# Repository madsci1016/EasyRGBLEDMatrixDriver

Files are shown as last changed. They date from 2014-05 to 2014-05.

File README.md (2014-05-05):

EasyRGBLEDMatrixDriver
======================

Super Easy Arduino based serial backpack driver board for 16 x 32 RGB LED Matrix panels found here: http://www.adafruit.com/products/420

The code and board  design will let you drive a 16x32 RGB LED matrix panel with a serial port, with some limitations. A example sketch for a master controller is included. 

Video Demo:  http://youtu.be/BNk5QkBuxNQ  

FEATURES:
Drive multiple panels off 1 serial port to create larger displays.

LIMITATIONS:
You only get half the resolution of the 16x32 pixel display, only 8x16 which is then scaled to 16x32
Refresh rate is limited by speed and number of displays on the Serial Port

This library runs off of an Arduino Pro/Uno which is NOT powerful enough to display video. It's really meant for animations, text, and Tetris among other things.  

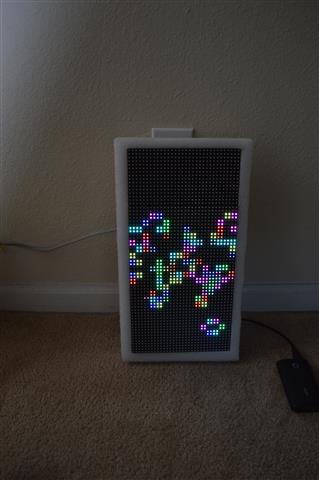
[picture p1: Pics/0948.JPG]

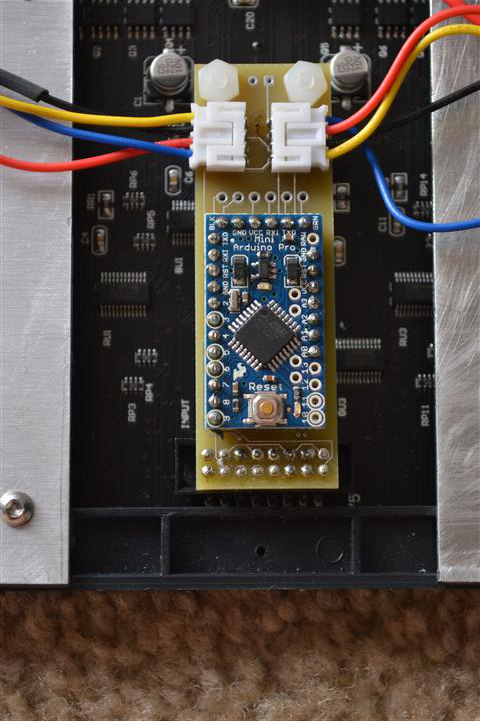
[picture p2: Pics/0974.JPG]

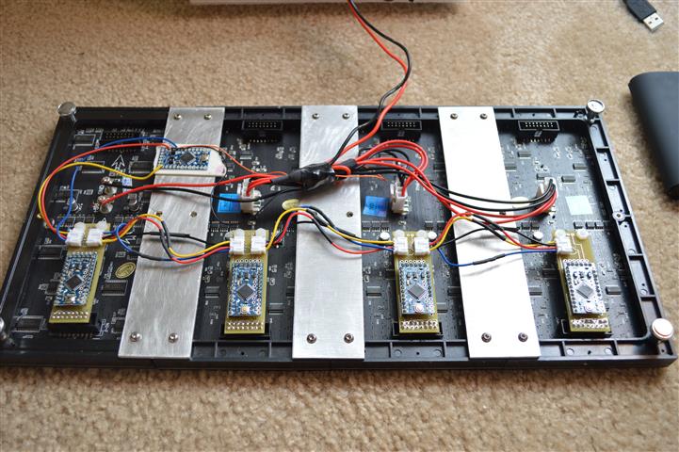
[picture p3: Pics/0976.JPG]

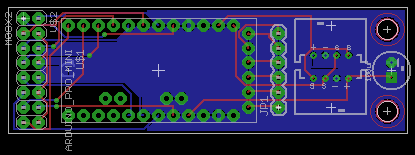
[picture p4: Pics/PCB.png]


In those pictures only 3 wires are shared by the 4 backpack Arduinos, 5V (Blue), GND (RED) and Data (Yellow) which is connected to the Serial RX of each Arduino (pin 1) the black wire (connected to TX of each Arduino) is not connected between each board. 

The 5th Arduino is the 'Master' and the Data line (Yellow) connects to it's Serial TX pin (Pin 0). 

Arduinos: https://www.sparkfun.com/products/11113
Wire and plug: https://www.sparkfun.com/products/9916

REQUIRES THE FOLLOWING LIBRARIES: 

https://github.com/adafruit/Adafruit-GFX-Library
https://github.com/adafruit/RGB-matrix-Panel
https://github.com/madsci1016/Arduino-EasyTransfer

To wire the display to the backpack arduino (Without my PCB), see:
https://learn.adafruit.com/32x16-32x32-rgb-led-matrix/wiring-the-16x32-matrix

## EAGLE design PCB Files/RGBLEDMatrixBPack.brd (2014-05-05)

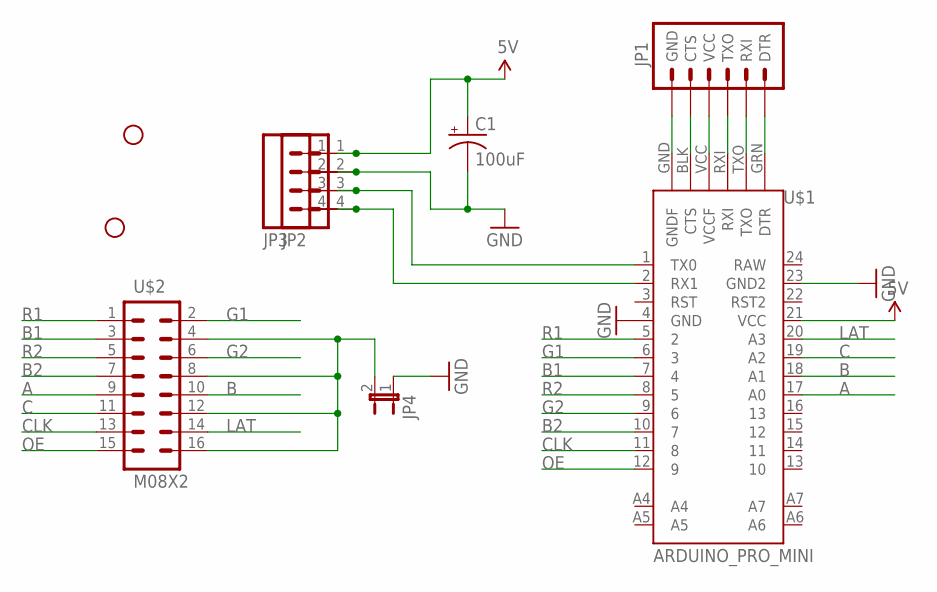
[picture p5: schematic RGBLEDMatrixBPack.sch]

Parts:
C1: 100uF; CPOL-RADIAL-100UF-25V
JP1: ARDUINO_SERIAL_PROGRAMPTH; 1X06
JP2, JP3: M04JST-PTH; JST-4-PTH
JP4: JUMPER-2SMD-NO; SJ_2S-NO
STANDOFF1, STANDOFF2: STAND-OFF
U$1: ARDUINO_PRO_MINI
U$2: M08X2; 2X8

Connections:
5V: C1.1 (+), JP2.1, JP3.1, U$1.21 (VCC)
A: U$1.17 (A0), U$2.9
B: U$1.18 (A1), U$2.10
B1: U$1.7 (4), U$2.3
B2: U$1.10 (7), U$2.7
C: U$1.19 (A2), U$2.11
CLK: U$1.11 (8), U$2.13
G1: U$1.6 (3), U$2.2
G2: U$1.9 (6), U$2.6
GND: C1.2 (-), JP2.2, JP3.2, JP4.1, U$1.4 (GND), U$1.23 (GND2)
LAT: U$1.20 (A3), U$2.14
unnamed: JP1.1 (DTR), U$1.GRN (DTR)
unnamed: JP1.2 (RXI), U$1.TXO
unnamed: JP1.3 (TXO), U$1.RXI
unnamed: JP1.4 (VCC), U$1.VCC (VCCF)
unnamed: JP1.5 (CTS), U$1.BLK (CTS)
unnamed: JP1.6 (GND), U$1.GND (GNDF)
unnamed: JP2.4, JP3.4, U$1.2 (RX1)
unnamed: JP2.3, JP3.3, U$1.1 (TX0)
unnamed: JP4.2, U$2.4, U$2.8, U$2.12, U$2.16
OE: U$1.12 (9), U$2.15
R1: U$1.5 (2), U$2.1
R2: U$1.8 (5), U$2.5

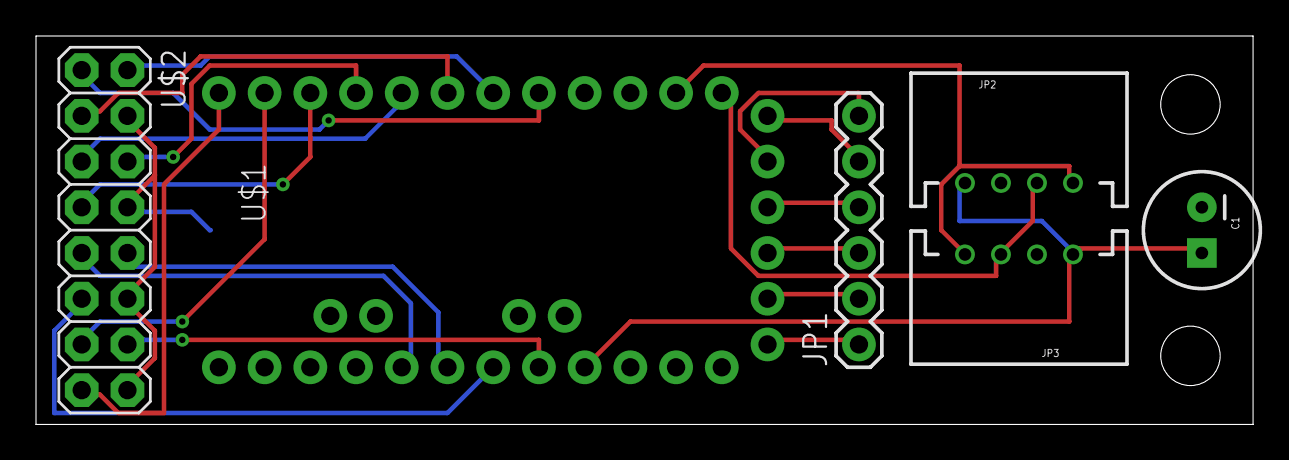
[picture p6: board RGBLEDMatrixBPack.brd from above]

Board: 2 copper layers, 67.6 x 21.6 mm, 9 parts (1 on the bottom side), 23 nets.

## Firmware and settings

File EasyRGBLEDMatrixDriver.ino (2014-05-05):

// EasyRGBLEDMatrixDriver
// Super Easy Arduino based serial driver board for 16 x 32 RGB LED Matrix panels.
// Like:
// http://www.adafruit.com/products/420

// Written by Bill Porter
// www.billporter.info
// 
//  REQUIRES
//  https://github.com/adafruit/Adafruit-GFX-Library
//  https://github.com/adafruit/RGB-matrix-Panel
//  https://github.com/madsci1016/Arduino-EasyTransfer



// For multiple panel configurations, give each panel a unique address here
#define MYADDRESS 4

#include <Adafruit_GFX.h>   // Core graphics library
#include <RGBmatrixPanel.h> // Hardware-specific library
#include <EasyTransfer.h>

#define CLK 8  // MUST be on PORTB! (Use pin 11 on Mega)
#define LAT A3
#define OE  9
#define A   A0
#define B   A1 
#define C   A2
RGBmatrixPanel matrix(A, B, C, CLK, LAT, OE, false);


//create COMMS object
EasyTransfer ET; 

struct RECEIVE_DATA_STRUCTURE{
  //put your variable definitions here for the data you want to send
  //THIS MUST BE EXACTLY THE SAME ON THE OTHER ARDUINO
  byte address;
  byte displaydata[16][8];
} packet;

int color; //temp color variable

void setup() {

  matrix.begin();
  
  // draw a pixel in solid white
  matrix.drawPixel(0, 0, matrix.Color333(7, 7, 7)); 
  delay(500);
 
  // fix the screen with green
  matrix.fillRect(0, 0, 32, 16, matrix.Color333(0, 7, 0));
  delay(500);

  // draw a box in yellow
  matrix.drawRect(0, 0, 32, 16, matrix.Color333(7, 7, 0));
  delay(500);
  
  // draw an 'X' in red
  matrix.drawLine(0, 0, 31, 15, matrix.Color333(7, 0, 0));
  matrix.drawLine(31, 0, 0, 15, matrix.Color333(7, 0, 0));
  delay(500);
  
  // draw a blue circle
  matrix.drawCircle(7, 7, 7, matrix.Color333(0, 0, 7));
  delay(500);
  
  // fill a violet circle
  matrix.fillCircle(23, 7, 7, matrix.Color333(7, 0, 7));
  delay(500);
  
  // fill the screen with 'black'
  matrix.fillScreen(matrix.Color333(0, 0, 0));
  
  // draw some text!
  matrix.setCursor(1, 0);   // start at top left, with one pixel of spacing
  matrix.setTextSize(1);    // size 1 == 8 pixels high
  
  // print each letter with a rainbow color
  matrix.setTextColor(matrix.Color333(7,0,0));
  matrix.print('1');
  matrix.setTextColor(matrix.Color333(7,4,0)); 
  matrix.print('6');
  matrix.setTextColor(matrix.Color333(7,7,0));
  matrix.print('x');
  matrix.setTextColor(matrix.Color333(4,7,0)); 
  matrix.print('3');
  matrix.setTextColor(matrix.Color333(0,7,0));  
  matrix.print('2');
  
  matrix.setCursor(1, 9);   // next line
  matrix.setTextColor(matrix.Color333(0,7,7)); 
  matrix.print('*');
  matrix.setTextColor(matrix.Color333(0,4,7)); 
  matrix.print('R');
  matrix.setTextColor(matrix.Color333(0,0,7));
  matrix.print('G');
  matrix.setTextColor(matrix.Color333(4,0,7)); 
  matrix.print("B");
  matrix.setTextColor(matrix.Color333(7,0,4)); 
  matrix.print("*");
  
  delay(500);
  matrix.fillScreen(matrix.Color333(0, 0, 0));
  

 
 Serial.begin(57600);
 ET.begin(details(packet), &Serial);
 
  // whew!
}

void loop() {
  
  if(ET.receiveData()){
    //got packet, check address
    if(packet.address == 0) {
      //global address, listen to data
      //we have to scale up to our full resolution. 
      
       for (int i = 0; i < 16; i++) {
        for (int j = 0; j < 8; j++) {
          //color needs to be promoted to Adafruit_GFX 5/6/5
          color = (((packet.displaydata[i][j] & 0b11100000) << 8) | ((packet.displaydata[i][j] & 0b00011100) << 6) | ((packet.displaydata[i][j] & 0b00000011) << 3));
            matrix.drawPixel(i*2, j*2, color);
            matrix.drawPixel(i*2+1, j*2, color);
            matrix.drawPixel(i*2, j*2+1, color);
            matrix.drawPixel(i*2+1, j*2+1, color);
          } 
       }
    }
    else if(packet.address == MYADDRESS){
      
      //ok, so we got data just for us. Let's shut the serial port down, and wait for a sync pulse. 
      Serial.end();
      pinMode(0, INPUT);
      
      //ttl idles high. Look for a sync pulse and timeout after 500ms. 
      long start = millis();
      
      while((millis() - start) < 500) {
       if(pulseIn(0, LOW) > 1000){
         //sync pulse received, put up data.
         for (int i = 0; i < 16; i++) {
          for (int j = 0; j < 8; j++) {
          //color needs to be promoted to Adafruit_GFX 5/6/5
            color = (((packet.displaydata[i][j] & 0b11100000) << 8) | ((packet.displaydata[i][j] & 0b00011100) << 6) | ((packet.displaydata[i][j] & 0b00000011) << 3));
            matrix.drawPixel(i*2, j*2, color);
            matrix.drawPixel(i*2+1, j*2, color);
            matrix.drawPixel(i*2, j*2+1, color);
            matrix.drawPixel(i*2+1, j*2+1, color);
          } 
         }
         
         //break out of while
         break;
       }
       
      }
      
      //restart serial
      Serial.begin(57600);
     
      
      
    }
  }
  
}
  
  

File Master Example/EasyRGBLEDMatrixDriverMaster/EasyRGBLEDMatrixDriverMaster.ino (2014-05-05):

// Demo for EasyRGBLEDMatrixDriver library.
// Demonstrates sending graphics data to 4 displays on 1 serial port. 

// Written by Bill Porter
// www.billporter.info
// 

/*
	This code is meant to be run on a 'Master Arduino' connected to 4 slave Arduino's acting as display backpacks. Serial TX line on this Ardunio should be connected to the Serial RX line of the other 4 Arduinos.
	This Demo flashes out a sequence of solid Red, then Blue, then Green 3 times followed by a Game of Life simulation. 
	
*/


#include <EasyTransfer.h>


// Variables For game of Life

#define SIZEX 16
#define SIZEY 32

byte analogPin = A5;
byte col = 0;
//byte repeat[SIZEX][SIZEY];
byte world[SIZEX][SIZEY][2];
byte  DELAY = 1;
byte colors[] = {0b11100000, 0b00011100, 0b00000011, 0b11111100, 0b11100011, 0b00011111, 0b11111111};

//Get comms ready
//create object
EasyTransfer ET; 

//I'm gonna implement an adressing scheme. Panels will be address 1,2,3,4.
//Panels will display any data matching their address
//All panels will listen to address 0

struct SEND_DATA_STRUCTURE{
  //put your variable definitions here for the data you want to send
  //THIS MUST BE EXACTLY THE SAME ON THE OTHER ARDUINO
  byte address;
  byte displaydata[16][8];
} packet;


//a big buffer representing the whole screen. GFX functions will write out to this. 
byte displaybuffer[16][32]; 

//Adafruit_GFX gfx(16,32);

void drawPixel(int x, int y, int c){
  
  displaybuffer[x][y] = c;
  
}


void setup() {

  
 randomSeed(analogRead(analogPin));
 
 Serial.begin(57600);
 ET.begin(details(packet), &Serial);
 
  // whew!
}

void loop() {
  
  //useful functions.
  //fillDisplay(color), sets all nodes to a single solid color. 
 //runSim(), runs game of life sim.
 
  
  
  fillDisplay(0b11100000);
  delay(500);
  fillDisplay(0b00000011);
  delay(500);
  fillDisplay(0b00011100);
  delay(500);
  fillDisplay(0);
  delay(2000);
  fillDisplay(0b11100000);
  delay(500);
  fillDisplay(0b00000011);
  delay(500);
  fillDisplay(0b00011100);
  delay(500);
  fillDisplay(0);
  delay(2000);
  fillDisplay(0b11100000);
  delay(500);
  fillDisplay(0b00000011);
  delay(500);
  fillDisplay(0b00011100);
  delay(500);
  fillDisplay(0);
  
  runSim();
  
  fillDisplay(0);
  delay(500);


}

//run game of life, break down display and send all nodes. 
void runSim(){
  
  beginLife();
  for(int i=0; i<100; i++){
    //run sim frame
    gameOfLife();
    //post frame to our multisegment display
    postFrame();
  
  }
}

//set whole screen to one color.
//use Global address to update all segments at once. 
void fillDisplay(byte color){
  
  for(int y=0; y<16; y++){
    for(int i=0; i<8; i++){
      packet.displaydata[y][i] = color;
      
    }
  }
  
  packet.address = 0;
  ET.sendData();
}

void postFrame(){
  //copy segments out of our world buffer, plane 0
  //send each segment using ET, then sync them together. 
  
  //i could do this in single block copy instructions, but I'd have to re-arrange my arrays to enable that. doin it the long way.
  
  for(int y=0; y<16; y++){
    for(int i=0; i<8; i++){
      packet.displaydata[y][i] = world[y][i][0];
      
    }
  }
  
  packet.address=1;
  
  Serial.flush();
  ET.sendData();
  
  for(int y=0; y<16; y++){
    for(int i=0; i<8; i++){
      packet.displaydata[y][i] = world[y][i+8][0];
      
    }
  }
  
  packet.address=2;
  
  Serial.flush();
  ET.sendData();
  
  for(int y=0; y<16; y++){
    for(int i=0; i<8; i++){
      packet.displaydata[y][i] = world[y][i+16][0];
      
    }
  }
  
  packet.address=3;
  
  Serial.flush();
  ET.sendData();
  
  for(int y=0; y<16; y++){
    for(int i=0; i<8; i++){
      packet.displaydata[y][i] = world[y][i+24][0];
      
    }
  }
  
  packet.address=4;
  
  Serial.flush();
  ET.sendData();
  
  Serial.flush();
    //send sync trigger
    //We are going to send a Pulse down the serial line to tell all drivers to post the data they received. 
  Serial.end();
  pinMode(1,OUTPUT);
  digitalWrite(1,HIGH);
  delayMicroseconds(500);
  digitalWrite(1,LOW);
  delayMicroseconds(1500);
  
  //restart serial port
  Serial.begin(57600);
  
}

void gameOfLife() {
  lifeAndDeath();
  //display here only posts data to our displaybuffer
  //actually, screw that. Let's have our postFrame() function copy directly out of world buffer. 
  //displayCurrentLife();
}


void beginLife() {
  long density = 42; 
  density += random(15);
  for (int i = 0; i < SIZEX; i++) {
    for (int j = 0; j < SIZEY; j++) {
      if (random(100) < density) {
        world[i][j][0] = 0b11100000;
      }
      else {
        world[i][j][0] = 0;
      }
      world[i][j][1] = 0;
    }
  }
}

void lifeAndDeath() {
  // Birth and death cycle
  for (int x = 0; x < SIZEX; x++) {
    for (int y = 0; y < SIZEY; y++) {
      // Default is for cell to stay the same
      world[x][y][1] = world[x][y][0];
      int count = neighbours(x, y);
      if (count == 3 && world[x][y][0] == 0) {
        // A new cell is born
        world[x][y][1] =  colors[random(6)] ; //0b00000011;
      }
      if ((count < 2 || count > 3) && world[x][y][0] >= 1) {
        // Cell dies
        world[x][y][1] = 0;
      }
    }
  }
  // Copy next generation into place
  for (int x = 0; x < SIZEX; x++) {
    for (int y = 0; y < SIZEY; y++) {
     // repeat[x][y] = world[x][y][0];
      world[x][y][0] = world[x][y][1];
    }
  }
}

void displayCurrentLife() {
  // Display current generation
  int color=0;
  int _counter = 0;
  int _death   = 0;
  for (int i = 0; i < SIZEX; i++) {
    for (int j = 0; j < SIZEY; j++) {
      if(world[i][j][0]) {
        //drawPixel(i,j, randColor(7));
        /* need to fix this color = matrix.Color333(world[i][j][0] >> 5, world[i][j][0] >> 2, (world[i][j][0] & 0b00000011) << 1);
        matrix.drawPixel(i*2, j*2, color);
        matrix.drawPixel(i*2+1, j*2, color);
        matrix.drawPixel(i*2, j*2+1, color);
        matrix.drawPixel(i*2+1, j*2+1, color);
      } 
      else {
        //drawPixel(i,j,cBlack);
        //matrix.drawPixel(i, j, matrix.Color333(0, 0, 0));
        color=0;
        matrix.drawPixel(i*2, j*2, color);
        matrix.drawPixel(i*2+1, j*2, color);
        matrix.drawPixel(i*2, j*2+1, color);
        matrix.drawPixel(i*2+1, j*2+1, color);*/
      } 
      world[i][j][1] = 0;
    }
  }
  delay(DELAY);
  //fillMatrix(cBlack);
  //matrix.fillScreen(matrix.Color333(0, 0, 0));
}

int neighbours(int x, int y) {
  
  int count=0;
  
  if (world[(x + 1) % SIZEX][y][0]) count ++;
  if (world[x][(y + 1) % SIZEY][0]) count ++;
  if (world[(x + SIZEX - 1) % SIZEX][y][0]) count ++;
  if (world[x][(y + SIZEY - 1) % SIZEY][0]) count ++;
  if (world[(x + 1) % SIZEX][(y + 1) % SIZEY][0]) count ++;
  if (world[(x + SIZEX - 1) % SIZEX][(y + 1) % SIZEY][0]) count ++; 
  if (world[(x + SIZEX - 1) % SIZEX][(y + SIZEY - 1) % SIZEY][0]) count ++;
  if (world[(x + 1) % SIZEX][(y + SIZEY - 1) % SIZEY][0]) count ++;
  
  
  return count;
}

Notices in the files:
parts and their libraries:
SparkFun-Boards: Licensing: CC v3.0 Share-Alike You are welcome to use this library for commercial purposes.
